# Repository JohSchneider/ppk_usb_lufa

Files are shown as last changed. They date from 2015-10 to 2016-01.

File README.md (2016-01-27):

# ppk_usb_lufa
Palm Portable Keyboard USB conversion
=====

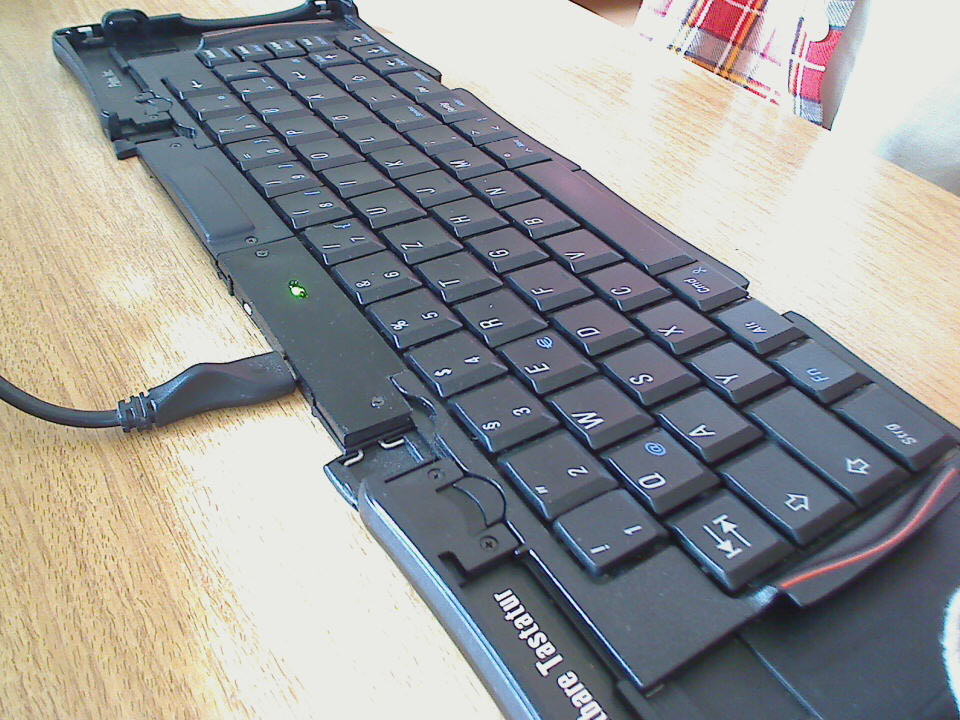
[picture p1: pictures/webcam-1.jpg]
keyboard


inspired by [this great project](http://www.cy384.com/projects/palm-keyboard.html) ([featured on Hackaday.com]([featured on HackADay](http://hackaday.com/2015/04/04/repurposing-a-palm-portable-keyboard/))

with the main goals/changes:
* keep electronics inside the fold-up case
* make it possible to use multimedia and other key-codes

the later was achieved by porting the arduino code to plain avr-c with lufa for the HID-keyboard handling and half a software serial implementation based on [application note avr309](http://www.atmel.com/Images/doc0941.pdf) (with code snippets [from here](http://www.element14.com/community/docs/DOC-56281/l/avr304-half-duplex-interrupt-driven-software-uart-on-tinyavr-and-megaavr-devices-coding))

parts list
----------
* Pololu A-Star Micro (https://www.pololu.com/product/3101) (a similar sized clone will probably do as well)
* 10k ohm 1/4W resistor
* slim tactile switch as the reset button (http://www.adafruit.com/products/1489)
* micro-usb breakout (http://www.adafruit.com/products/1833)
* wiring-pencil and wire
* 3D printed parts to replace the palm-dock

dis-assembly
---------
* remove the metal backplate on the left side (side with the palm-docking port) - take care not to cut yourself on the sharp edges
* remove the two screws connecting the fold-up stand to the keyboard followed by the two holding the docking-port
* free the flexible flat cable from the plastik parts (might need to cut some plastik away)
* desolder the spring-pins from the flat-cable

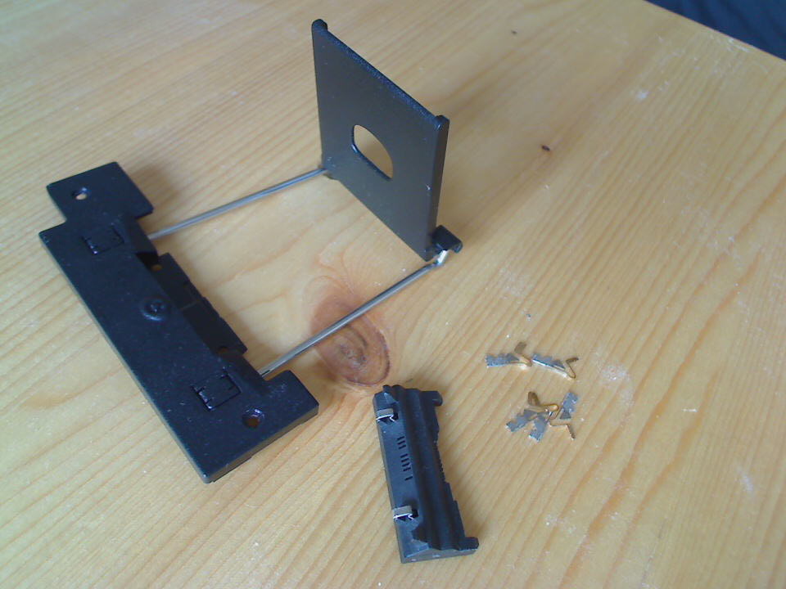
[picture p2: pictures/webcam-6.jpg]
ditched parts


* to be able to fit the Micro into the tight space its micro-usb plug needs to be desoldered (... fun)

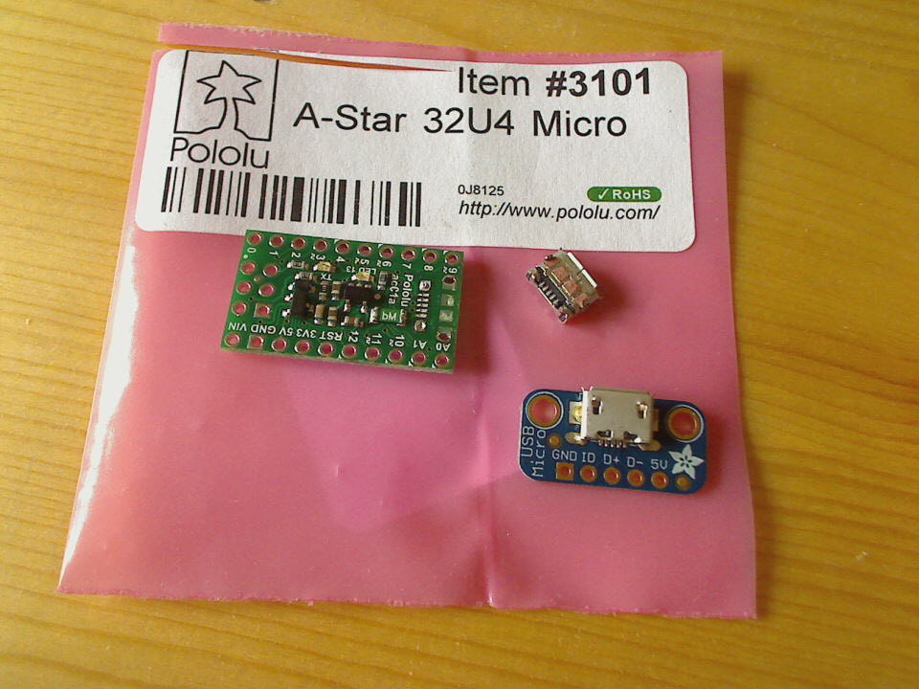
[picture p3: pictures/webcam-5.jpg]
desoldered micro-usb


wiring
--------
since these keyboards where built for multiple kinds of PDAs the dock-adapters had to be easily exchangable - that seems to be the reason why the flat cable running from the dock itself is joined to another "commmon" 6-wire flex cable with a special conductive tape that runs the remaining length around a bend to the keyboards pcb on the other side

this common flex cable has the following pinout
viewed from above - "through" the keyboard; from left to right:

Number | Name
---|---
 F1 | VCC
 F2 | RX_PIN
 F3 | RTS_PIN
 F4 | probably TX_PIN, unused anyway
 F5 | PIN_DCD
 F6 | GND

On the Micro the following pins are used:

flex cable | name | Micro Pin
--- | --- | ---
-|-|(reset to GND via the tactile switch)
 F1 | VCC | Pin 5
 F6 | GND | Pin 6
 F2 |  RX | Pin 3
 F3 | RTS | Pin 2
 F5 | DCD | Pin 4
-|-|pulldown resistor from Pin 8 to Pin 3

assembly
-------
* wire the usb-breakout to the Micro (in the final assembly the former usb port faces the micro-usb breakout)
* wire the Micro to the flex cable where the spring-pins of the docking connector used to be
* on the Micro board Gnd and Reset pins are spaced so that the reset button fits perfectly in between (covering +3V and +5V pins which need to be insulated!) putting the button on the board so that it sits flush 
* remove the support of the usb-port in the 3d printed part and *slightly* drill out the screw holes with a 3mm drill, so that the screw heads are flush with the surface
* fixing the Micro and the usb-breakout with some hot-melt glue to the 3d-printed part
* slide in the back-cover (might need to apply some heat to bend it a litte over the electronics, should close up flush with the other 3d printed part)

code compilation
---------
requires gcc-avr and avrdude to compile via the makefile

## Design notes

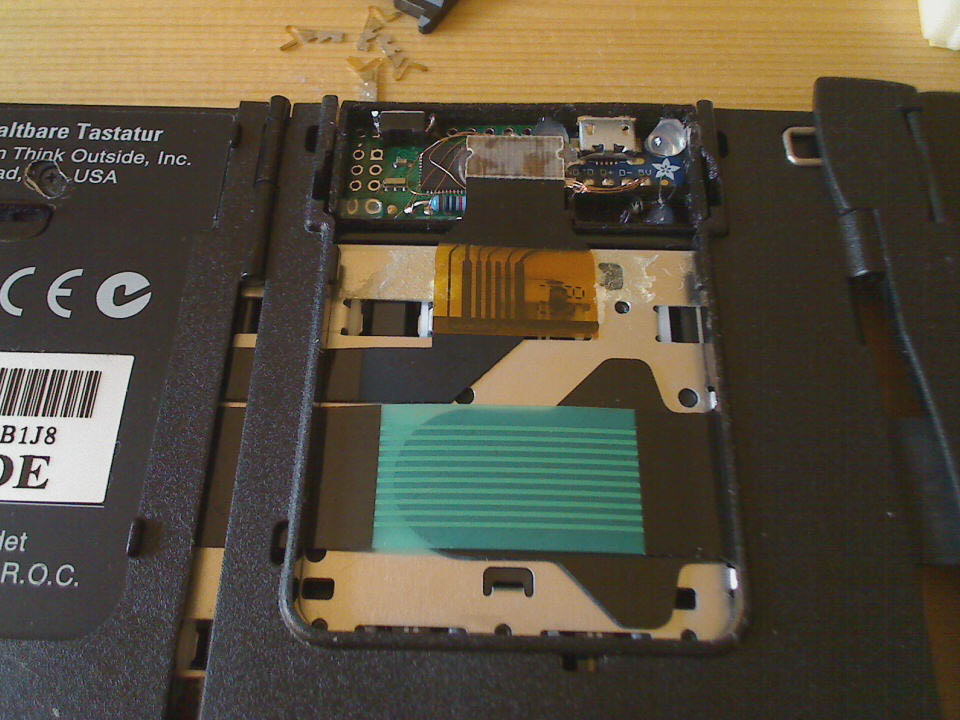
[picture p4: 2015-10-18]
pictures/webcam-7.jpg

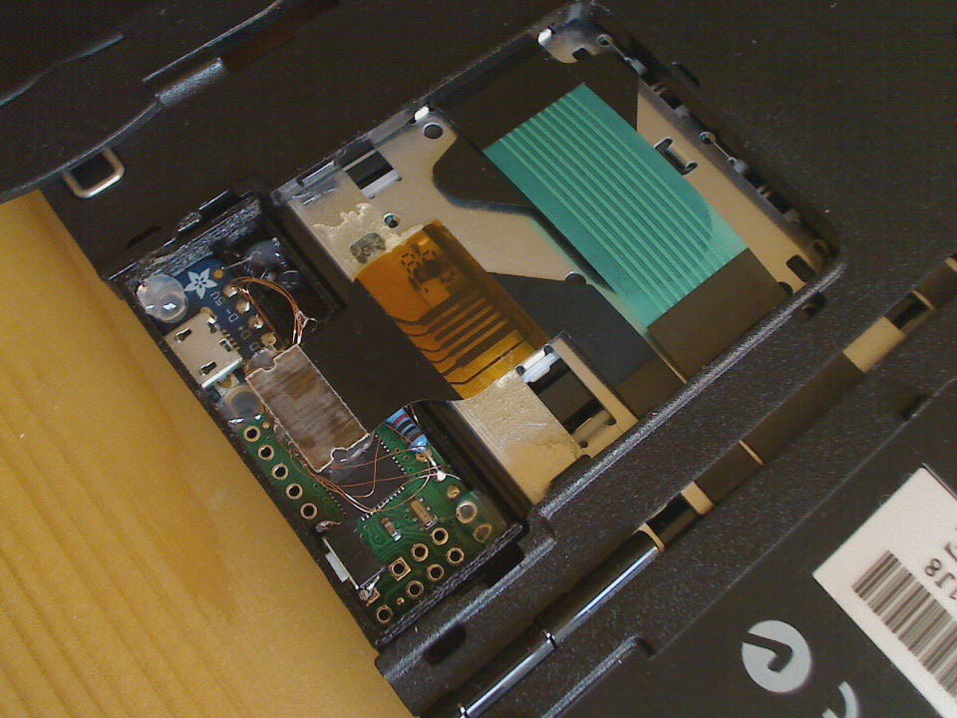
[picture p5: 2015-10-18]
pictures/webcam-8.jpg

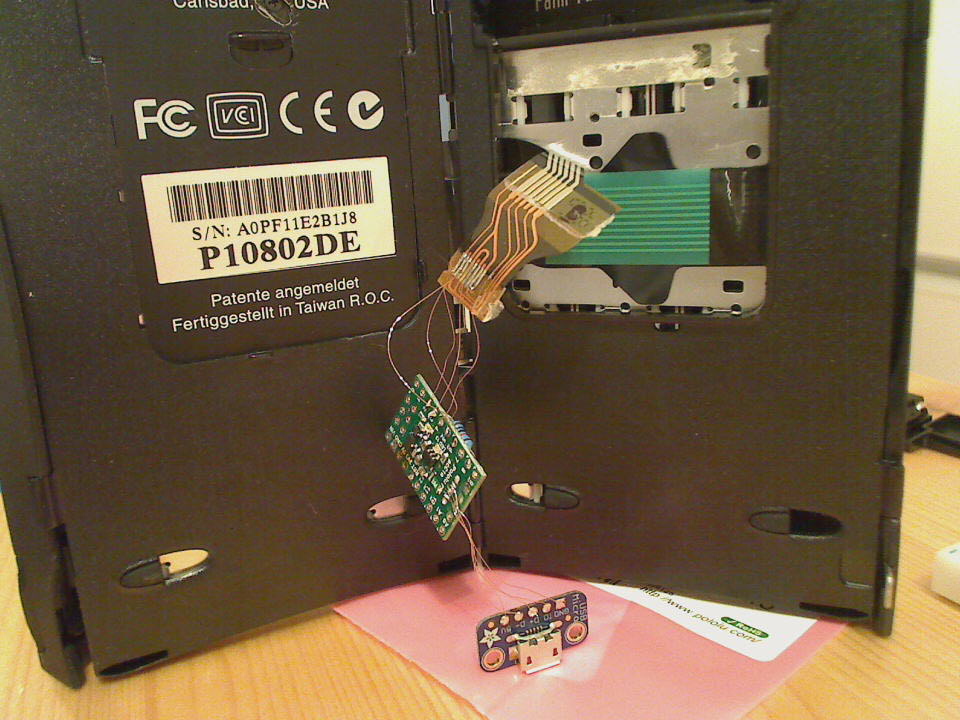
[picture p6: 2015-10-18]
pictures/webcam-3.jpg

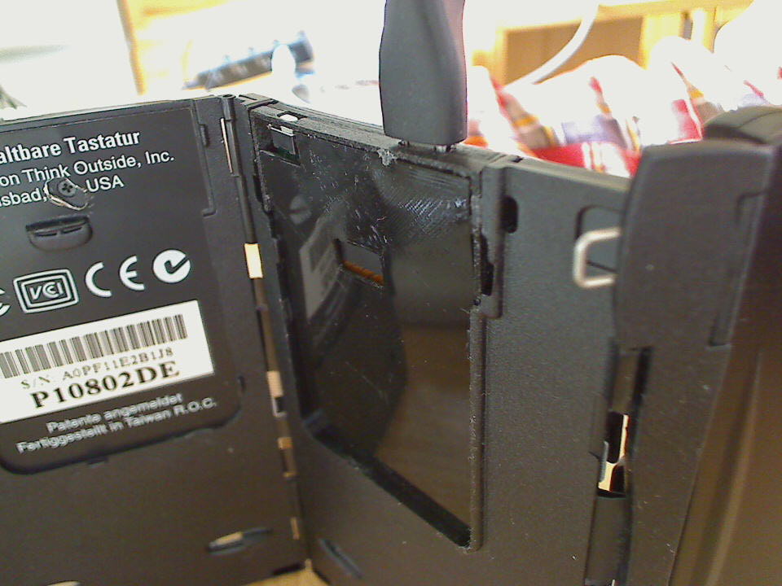
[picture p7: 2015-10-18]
pictures/webcam-4.jpg

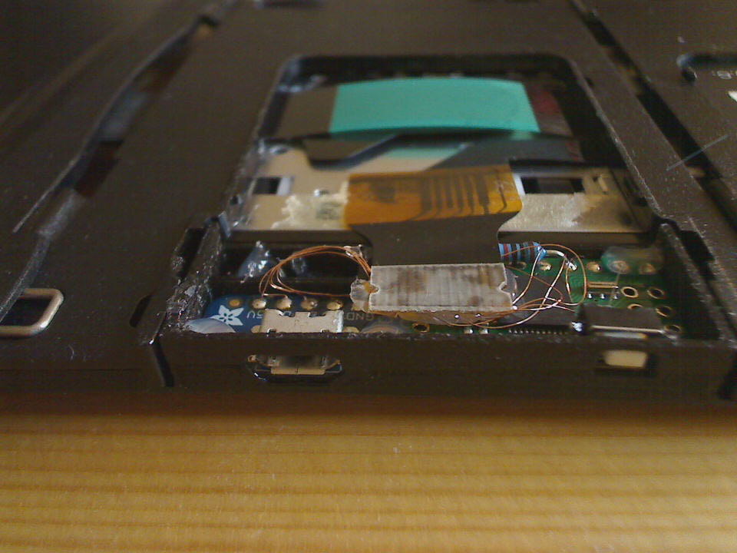
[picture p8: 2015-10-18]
pictures/webcam-9.jpg

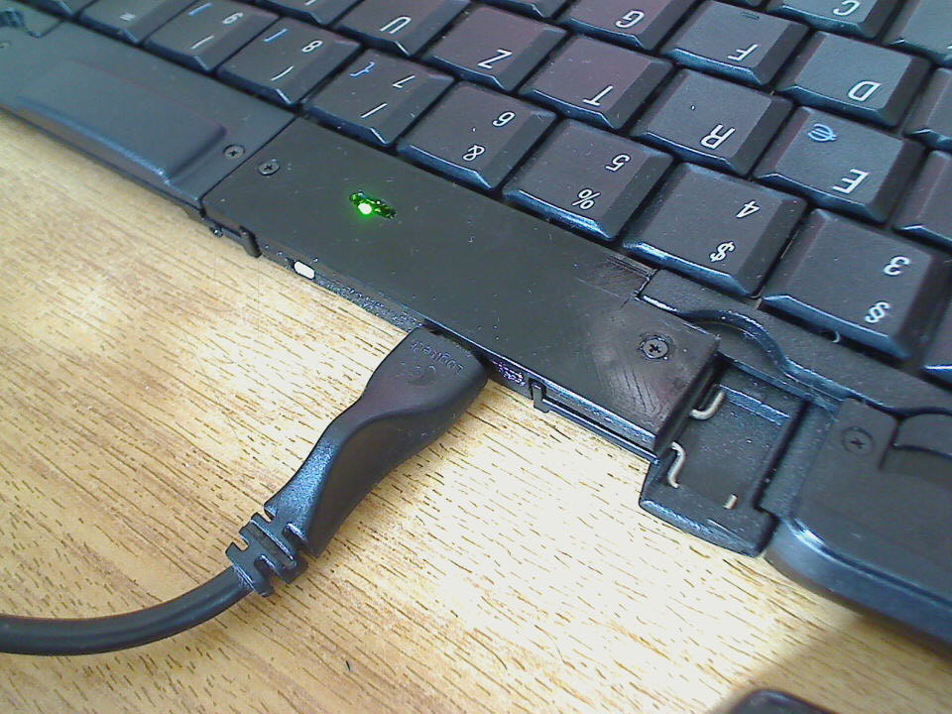
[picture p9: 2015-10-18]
pictures/webcam-2.jpg

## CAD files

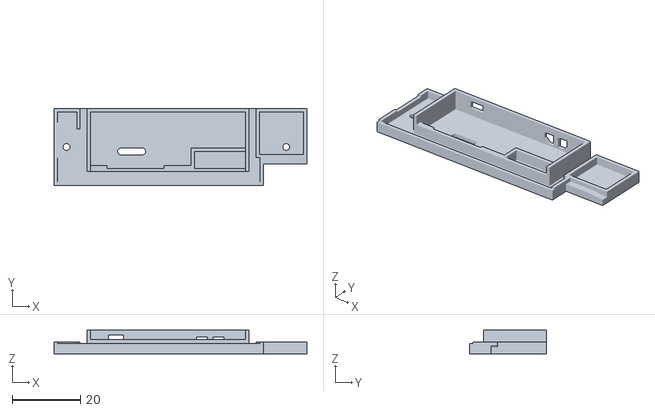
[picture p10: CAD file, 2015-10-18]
stls/palm_portable_keyboard_cover.stl
74.3 x 22.5 x 7.00

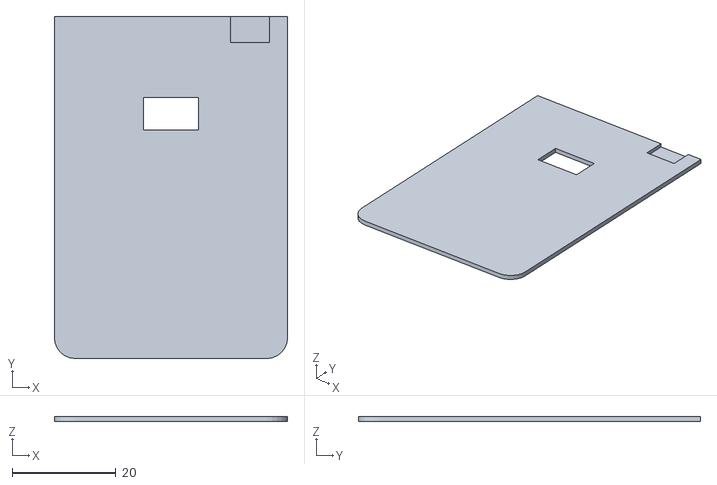
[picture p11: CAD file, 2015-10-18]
stls/palm_portable_keyboard_back_cover.stl
45.0 x 66.0 x 1.00

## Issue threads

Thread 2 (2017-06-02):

More details please and can I use a regular USB

rhubarb, 2017-06-02:
Great project: I have an old folding Palm V keyboard rendered obsolete within months of buying it and I'm itching to try out this hack.
I could use some more details though - some more photos (I can use a soldering iron but am not too experienced at this sort of hack).

Also, would it be possible to fit a regular USB on the kb, to allow reuse of a charging cable?

JohSchneider, 2017-06-07:
thnx!

maybe this is what your looking for?
https://hackaday.io/project/8107-palm-portable-keyboard-usb-mod

if a "regular usb" = USB a socket then probably no... space is quite limited
the pololu-a star micro comes with a micro-usb (which is currently more or less "the regular usb connector")

JohSchneider, 2017-06-07:
what kind of details are you looking for specifically?

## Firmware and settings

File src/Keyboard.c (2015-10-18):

/*
             LUFA Library
     Copyright (C) Dean Camera, 2015.

  dean [at] fourwalledcubicle [dot] com
           www.lufa-lib.org
*/

/*
  Copyright 2015  Dean Camera (dean [at] fourwalledcubicle [dot] com)

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
  The author disclaims all warranties with regard to this
  software, including all implied warranties of merchantability
  and fitness.  In no event shall the author be liable for any
  special, indirect or consequential damages or any damages
  whatsoever resulting from loss of use, data or profits, whether
  in an action of contract, negligence or other tortious action,
  arising out of or in connection with the use or performance of
  this software.
*/

/** \file
 *
 *  Main source file for the Keyboard demo. This file contains the main tasks of
 *  the demo and is responsible for the initial application hardware configuration.
 */

#include "Keyboard.h"

/** Buffer to hold the previously generated Keyboard HID report, for comparison purposes inside the HID class driver. */
static uint8_t PrevKeyboardHIDReportBuffer[sizeof(USB_KeyboardReport_Data_t)];

/** LUFA HID Class driver interface configuration and state information. This structure is
 *  passed to all HID Class driver functions, so that multiple instances of the same class
 *  within a device can be differentiated from one another.
 */
USB_ClassInfo_HID_Device_t Keyboard_HID_Interface =
	{
		.Config =
			{
				.InterfaceNumber              = INTERFACE_ID_Keyboard,
				.ReportINEndpoint             =
					{
						.Address              = KEYBOARD_EPADDR,
						.Size                 = KEYBOARD_EPSIZE,
						.Banks                = 1,
					},
				.PrevReportINBuffer           = PrevKeyboardHIDReportBuffer,
				.PrevReportINBufferSize       = sizeof(PrevKeyboardHIDReportBuffer),
			},
	};


/** Main program entry point. This routine contains the overall program flow, including initial
 *  setup of all components and the main program loop.
 */
int main(void)
{
	SetupHardware();

//	LEDs_SetAllLEDs(LEDMASK_USB_NOTREADY);
	LEDs_SetAllLEDs(0);

	GlobalInterruptEnable();

	BootKeyboard();

	for (;;)
	{
	  ProcessKeyboardSerialByte();
		HID_Device_USBTask(&Keyboard_HID_Interface);
		USB_USBTask();
	}
}

/** Configures the board hardware and chip peripherals for the demo's functionality. */
void SetupHardware()
{
	/* Disable watchdog if enabled by bootloader/fuses */
	MCUSR &= ~(1 << WDRF);
	wdt_disable();

	/* Disable clock division */
	clock_prescale_set(clock_div_1);


	/* Hardware Initialization */

	initSoftwareUart();

	// setup timer1 to keep the keyboard awake
	TCCR1B = (1<<CS12) | (1<<CS10); // prescaler 1024
	TCCR1B |= (1 << WGM12); // CTC mode
	TIMSK1 = 1<<OCIE1A; // trigger interrupt on compare
	OCR1A = 15624; // once per second
	// we run at 16Mhz:
	// timer counts + 1 = (target time) / (timer resolution)
	//   timer resolution = 1/(16Mhz / 1024)  seconds
	// => OCR1A = 1s * 1/( 16Mhz / 1024 ) -1 = 15624

	// setup remaining pins
	//// DCD_PIN
	// a-star micro Pin 4 -> PD4
	DDRD &= ~DCD_PIN; // set input
	//// RTS_PIN
	// a-star micro Pin 2 -> PD1
	DDRD &= ~RTS_PIN; // set input
	//// PULLDOWN_PIN
	// a-star micro Pin 8 -> PB4
	DDRB |= PULLDOWN_PIN; // set output
	PORTB &= ~PULLDOWN_PIN; // set LOW
	//// VCC_PIN
	// a-star micro Pin 5 -> PC6
	DDRC |= VCC_PIN;
	PORTC &= ~VCC_PIN;
	//// GND_PIN
	// a-star micro Pin 6 -> PD7
	DDRD |= GND_PIN;
	PORTD &= ~GND_PIN;

	USB_Init();
}

void BootKeyboard(void)
{
  PORTC &= ~VCC_PIN; // power off
  _delay_ms(5);
  PORTC |= VCC_PIN; // power on
  _delay_ms(15);

  // wait until the keyboard has powerd on, it signals this by pulling DCD_PIN high..
  while(!(PIND & DCD_PIN)) {;}
  //.. and then expects the driver to pull RTS high
  if (!(PIND & RTS_PIN)) { // if we read low
    DDRD |= RTS_PIN; // set pin to output
    PORTD |= RTS_PIN; // and high
  }
  else {
    DDRD |= RTS_PIN; // set pin to output
    PORTD &= ~RTS_PIN; // low
    _delay_ms(10);
    PORTD |= RTS_PIN; // high
  }

  _delay_ms(5);

  // wait for the keyboard to send its id string (the first two bytes)
  while (SwUartRXData != 0xFA) {;}
  while (SwUartRXData != 0xFD) {;}
}


/* keyboard goes to non-responsive sleep after 10 minutes of no keypresses and RTS on high
 * so we toggle RTS every 7 minutes regardless of input just to keep it on its toes :-)
 */
ISR(TIMER1_COMPA_vect)
{
  seconds++;
  if (seconds == 60*7)
    {
      DDRD |= RTS_PIN; // set pin to output
      PORTD &= ~RTS_PIN; // low
      _delay_ms(10);
      PORTD |= RTS_PIN; // high
      seconds = 0;
    }
}


/** press a normal key (e.g. not a modifier key) */
void pressKey(uint8_t raw, uint8_t key)
{
  if (UsedKeyCodes < 6)
    {
      UsedKeyCodes++;
      pressedRawKeyCode[UsedKeyCodes] = raw;
      KeyboardReport.KeyCode[UsedKeyCodes] = key;
    }
}

  /** release a normal, non-modifier key */
void releaseKey(uint8_t raw)
{
  // check which of the pressed KeyCode has been released
  for (int i=0; i<6; i++)
    {
      if (pressedRawKeyCode[i] == raw)
	{
	  // move remaining one place up
	  for (int j=i; j<5; j++)
	    {
	      KeyboardReport.KeyCode[j] = KeyboardReport.KeyCode[j+1];
	      pressedRawKeyCode[j] = pressedRawKeyCode[j+1];
	    }
	  // and put an empty in the last place
	  KeyboardReport.KeyCode[5] = 0;
	  pressedRawKeyCode[5] = 255;
	  UsedKeyCodes--;
	}
    }
}

void ProcessKeyboardSerialByte(void)
{
  if( state == DATA_PENDING )
    {
	      unsigned char keyUpDown = SwUartRXData & 0b10000000;
	      unsigned char keyXY = SwUartRXData & 0b01111111;
	      state = IDLE;
	      seconds = 0; // reset keep awake watchdog

	      // for a table of available keycode defines see:
	      // LUFA/Drivers/USB/Class/Common/HIDClassCommon.h

	      if (keyUpDown) // true: key released
		{
		if (lastByte == SwUartRXData)
		  {
		    // releaseAll
		    // memset(&KeyboardReport, 0, sizeof(USB_KeyboardReport_Data_t));
		    KeyboardReport.KeyCode[0] = 0;
		    KeyboardReport.KeyCode[1] = 0;
		    KeyboardReport.KeyCode[2] = 0;
		    KeyboardReport.KeyCode[3] = 0;
		    KeyboardReport.KeyCode[4] = 0;
		    KeyboardReport.KeyCode[5] = 0;
		    KeyboardReport.Modifier = 0;
		    UsedKeyCodes = 0;
		  }
		else
		  {
		    switch (keyXY)
		      {
		      case 0b00100010: // FN
			FN_pressed = 0;
			break;
		      case 0b00001000: // "CMD"
			releaseKey(keyXY);
			// TODO: is it okay to set the modifier flag and press the key at the same time?
			KeyboardReport.Modifier &= ~HID_KEYBOARD_MODIFIER_LEFTGUI;
			break;
		      case 0b00011010: // CTRL (only left one exists)
			KeyboardReport.Modifier &= ~HID_KEYBOARD_MODIFIER_LEFTCTRL;
			break;
		      case 0b00100011: // ALT (only left one exists)
			KeyboardReport.Modifier &= ~HID_KEYBOARD_MODIFIER_LEFTALT;
			break;
		      case 0b01011000: // SHIFT (L)
			KeyboardReport.Modifier &= ~HID_KEYBOARD_MODIFIER_LEFTSHIFT;
			break;
		      case 0b01011001: // SHIFT (R)
			KeyboardReport.Modifier &= ~HID_KEYBOARD_MODIFIER_RIGHTSHIFT;
			break;
		      default:
			releaseKey(keyXY);
		      }
		  }
		}
	      else // key pressed
	      switch(keyXY) {
		// y0 row
	      case 0b00000000: // '1'
		if (FN_pressed)
		  pressKey(keyXY, HID_KEYBOARD_SC_F1);
		else
		  pressKey(keyXY, HID_KEYBOARD_SC_1_AND_EXCLAMATION);
		break;
	      case 0b00000001: // '2'
		if (FN_pressed)
		  pressKey(keyXY, HID_KEYBOARD_SC_F2);
		else
		  pressKey(keyXY, HID_KEYBOARD_SC_2_AND_AT);
		break;
	      case 0b00000010: // '3'
		if (FN_pressed)
		  pressKey(keyXY, HID_KEYBOARD_SC_F3);
		else
		  pressKey(keyXY, HID_KEYBOARD_SC_3_AND_HASHMARK);
		break;
	      case 0b00000011: // 'z'
		pressKey(keyXY, HID_KEYBOARD_SC_Z);
		break;
	      case 0b00000100: // '4'
		if (FN_pressed)
		  pressKey(keyXY, HID_KEYBOARD_SC_F4);
		else
		  pressKey(keyXY, HID_KEYBOARD_SC_4_AND_DOLLAR);
		break;
	      case 0b00000101: // '5'
		if (FN_pressed)
		  pressKey(keyXY, HID_KEYBOARD_SC_F5);
		else
		  pressKey(keyXY, HID_KEYBOARD_SC_5_AND_PERCENTAGE);
		break;
	      case 0b00000110: // '6'
		if (FN_pressed)
		  pressKey(keyXY, HID_KEYBOARD_SC_F6);
		else
		  pressKey(keyXY, HID_KEYBOARD_SC_6_AND_CARET);
		break;
	      case 0b00000111: // '7'
		if (FN_pressed)
		  pressKey(keyXY, HID_KEYBOARD_SC_F7);
		else
		  pressKey(keyXY, HID_KEYBOARD_SC_7_AND_AMPERSAND);
		break;

		// y1 row
	      case 0b00001000: // "CMD"
		pressKey(keyXY, HID_KEYBOARD_SC_LEFT_GUI);
// TODO: is it okay to set the modifier flag and press the key at the same time?
		KeyboardReport.Modifier |= HID_KEYBOARD_MODIFIER_LEFTGUI;
		break;
	      case 0b00001001: // 'q'
		pressKey(keyXY, HID_KEYBOARD_SC_Q);
		break;
	      case 0b00001010: // 'w'
		pressKey(keyXY, HID_KEYBOARD_SC_W);
		break;
	      case 0b00001011: // 'e'
		pressKey(keyXY, HID_KEYBOARD_SC_E);
		break;
	      case 0b00001100: // 'r'
		pressKey(keyXY, HID_KEYBOARD_SC_R);
		break;
	      case 0b00001101: // 't'
		pressKey(keyXY, HID_KEYBOARD_SC_T);
		break;
	      case 0b00001110: // 'y'
		pressKey(keyXY, HID_KEYBOARD_SC_Y);
		break;
	      case 0b00001111: // two right of space-bar
		pressKey(keyXY, HID_KEYBOARD_SC_NON_US_BACKSLASH_AND_PIPE);  // physical row 5, 7th key
		break;

		// y2 row
	      case 0b00010000: // 'x'
		pressKey(keyXY, HID_KEYBOARD_SC_X);
		break;
	      case 0b00010001: // 'a'
		pressKey(keyXY, HID_KEYBOARD_SC_A);
		break;
	      case 0b00010010: // 's'
		pressKey(keyXY, HID_KEYBOARD_SC_S);
		break;
	      case 0b00010011: // 'd'
		pressKey(keyXY, HID_KEYBOARD_SC_D);
		break;
	      case 0b00010100: // 'f'
		pressKey(keyXY, HID_KEYBOARD_SC_F);
		break;
	      case 0b00010101: // 'g'
		pressKey(keyXY, HID_KEYBOARD_SC_G);
		break;
	      case 0b00010110: // 'h'
		pressKey(keyXY, HID_KEYBOARD_SC_H);
		break;
	      case 0b00010111: // ' ' // "Space 1"
		pressKey(keyXY, HID_KEYBOARD_SC_SPACE);
		break;

		// y3 row
	      case 0b00011000: // CAPS LK
		pressKey(keyXY, HID_KEYBOARD_SC_CAPS_LOCK);
		break;
	      case 0b00011001: // TAB
		pressKey(keyXY, HID_KEYBOARD_SC_TAB);
		break;
	      case 0b00011010: // CTRL (only left one exists)
		KeyboardReport.Modifier |= HID_KEYBOARD_MODIFIER_LEFTCTRL;
		break;

		// y4 row
	      case 0b00100010: // FN
		FN_pressed = 1;
		break;
	      case 0b00100011: // ALT (only left one exists)
		KeyboardReport.Modifier |= HID_KEYBOARD_MODIFIER_LEFTALT;
		break;

		// y5 row
	      case 0b00101100: // 'c'
		pressKey(keyXY, HID_KEYBOARD_SC_C);
		break;
	      case 0b00101101: // 'v'
		pressKey(keyXY, HID_KEYBOARD_SC_V);
		break;
	      case 0b00101110: // 'b'
		pressKey(keyXY, HID_KEYBOARD_SC_B);
		break;
	      case 0b00101111: // 'n'
		pressKey(keyXY, HID_KEYBOARD_SC_N);
		break;

		// y6 row
	      case 0b00110000: // '-'
		if (FN_pressed)
		  pressKey(keyXY, HID_KEYBOARD_SC_F11);
		else
		  pressKey(keyXY, HID_KEYBOARD_SC_MINUS_AND_UNDERSCORE);
		break;
	      case 0b00110001: // '='
		if (FN_pressed)
		  pressKey(keyXY, HID_KEYBOARD_SC_F12);
		else
		  pressKey(keyXY, HID_KEYBOARD_SC_EQUAL_AND_PLUS);
		break;
	      case 0b00110010: // BACK SP
		pressKey(keyXY, HID_KEYBOARD_SC_BACKSPACE);
		break;
	      case 0b00110011: // "Special Function One"
		pressKey(keyXY, HID_KEYBOARD_SC_MEDIA_NEXT_TRACK);
		break;
	      case 0b00110100: // '8'
		if (FN_pressed)
		  pressKey(keyXY, HID_KEYBOARD_SC_F8);
		else
		  pressKey(keyXY, HID_KEYBOARD_SC_8_AND_ASTERISK);
		break;
	      case 0b00110101: // '9'
		if (FN_pressed)
		  pressKey(keyXY, HID_KEYBOARD_SC_F9);
		else
		  pressKey(keyXY, HID_KEYBOARD_SC_9_AND_OPENING_PARENTHESIS);
		break;
	      case 0b00110110: // '0'
		if (FN_pressed)
		  pressKey(keyXY, HID_KEYBOARD_SC_F10);
		else
		  pressKey(keyXY, HID_KEYBOARD_SC_0_AND_CLOSING_PARENTHESIS);
		break;
	      case 0b00110111: // "Space 2" - Note: right of space-bar
		pressKey(keyXY, HID_KEYBOARD_SC_GRAVE_ACCENT_AND_TILDE); // physical row 5, 6th key
		break;

		// y7 row
	      case 0b00111000: // '['
		pressKey(keyXY, HID_KEYBOARD_SC_OPENING_BRACKET_AND_OPENING_BRACE);
		break;
	      case 0b00111001: // ']'
		pressKey(keyXY, HID_KEYBOARD_SC_CLOSING_BRACKET_AND_CLOSING_BRACE);
		break;
	      case 0b00111010: // '\'
		pressKey(keyXY, HID_KEYBOARD_SC_BACKSLASH_AND_PIPE);
		break;
	      case 0b00111011: // "Special Function Two"
		pressKey(keyXY, HID_KEYBOARD_SC_MEDIA_PREVIOUS_TRACK);
		break;
	      case 0b00111100: // 'u'
		pressKey(keyXY, HID_KEYBOARD_SC_U);
		break;
	      case 0b00111101: // 'i'
		pressKey(keyXY, HID_KEYBOARD_SC_I);
		break;
	      case 0b00111110: // 'o'
		pressKey(keyXY, HID_KEYBOARD_SC_O);
		break;
	      case 0b00111111: // 'p'
		pressKey(keyXY, HID_KEYBOARD_SC_P);
		break;

		// y8 row
	      case 0b01000000: // '''
		pressKey(keyXY, HID_KEYBOARD_SC_APOSTROPHE_AND_QUOTE);
		break;
	      case 0b01000001: // ENTER
		pressKey(keyXY, HID_KEYBOARD_SC_ENTER);
		break;
	      case 0b01000010: // "Special Function Three"
		pressKey(keyXY, HID_KEYBOARD_SC_MEDIA_VOLUME_UP);
		break;
	      case 0b01000100: // 'j'
		pressKey(keyXY, HID_KEYBOARD_SC_J);
		break;
	      case 0b01000101: // 'k'
		pressKey(keyXY, HID_KEYBOARD_SC_K);
		break;
	      case 0b01000110: // 'l'
		pressKey(keyXY, HID_KEYBOARD_SC_L);
		break;
	      case 0b01000111: // ';'
		pressKey(keyXY, HID_KEYBOARD_SC_SEMICOLON_AND_COLON);
		break;

		// y9 row
	      case 0b01001000: // '?'
		pressKey(keyXY, HID_KEYBOARD_SC_SLASH_AND_QUESTION_MARK);
		break;
	      case 0b01001001: // up arrow
		if (FN_pressed)
		  pressKey(keyXY, HID_KEYBOARD_SC_PAGE_UP);
		else
		  pressKey(keyXY, HID_KEYBOARD_SC_UP_ARROW);
		break;
	      case 0b01001010: // "Special Function Four"
		pressKey(keyXY, HID_KEYBOARD_SC_MEDIA_VOLUME_DOWN);
		break;
	      case 0b01001100: // 'm'
		pressKey(keyXY, HID_KEYBOARD_SC_M);
		break;
	      case 0b01001101: // ','
		pressKey(keyXY, HID_KEYBOARD_SC_COMMA_AND_LESS_THAN_SIGN);
		break;
	      case 0b01001110: // '.'
		pressKey(keyXY, HID_KEYBOARD_SC_DOT_AND_GREATER_THAN_SIGN);
		break;
	      case 0b01001111: // "DONE"
		pressKey(keyXY, HID_KEYBOARD_SC_ESCAPE);
		break;

		// y10 row
	      case 0b01010000: // DEL
		if (FN_pressed)
		  pressKey(keyXY, HID_KEYBOARD_SC_INSERT);
		else
		  pressKey(keyXY, HID_KEYBOARD_SC_DELETE);
		break;
	      case 0b01010001: // left arrow
		if (FN_pressed)
		  pressKey(keyXY, HID_KEYBOARD_SC_HOME);
		else
		  pressKey(keyXY, HID_KEYBOARD_SC_LEFT_ARROW);
		break;
	      case 0b01010010: // down arrow
		if (FN_pressed)
		  pressKey(keyXY, HID_KEYBOARD_SC_PAGE_DOWN);
		else
		  pressKey(keyXY, HID_KEYBOARD_SC_DOWN_ARROW);
		break;
	      case 0b01010011: // right arrow
		if (FN_pressed)
		  pressKey(keyXY, HID_KEYBOARD_SC_END);
		else
		  pressKey(keyXY, HID_KEYBOARD_SC_RIGHT_ARROW);
		break;

		// y11 row
	      case 0b01011000: // SHIFT (L)
		KeyboardReport.Modifier |= HID_KEYBOARD_MODIFIER_LEFTSHIFT;
		break;
	      case 0b01011001: // SHIFT (R)
		KeyboardReport.Modifier |= HID_KEYBOARD_MODIFIER_RIGHTSHIFT;
		break;
	      }

	      lastByte = SwUartRXData;
	  }
}


/** Event handler for the library USB Connection event. */
void EVENT_USB_Device_Connect(void)
{
//	LEDs_SetAllLEDs(LEDMASK_USB_ENUMERATING);
}

/** Event handler for the library USB Disconnection event. */
void EVENT_USB_Device_Disconnect(void)
{
//	LEDs_SetAllLEDs(LEDMASK_USB_NOTREADY);
}

/** Event handler for the library USB Configuration Changed event. */
void EVENT_USB_Device_ConfigurationChanged(void)
{
	bool ConfigSuccess = true;

	ConfigSuccess &= HID_Device_ConfigureEndpoints(&Keyboard_HID_Interface);

	USB_Device_EnableSOFEvents();

//	LEDs_SetAllLEDs(ConfigSuccess ? LEDMASK_USB_READY : LEDMASK_USB_ERROR);
}

/** Event handler for the library USB Control Request reception event. */
void EVENT_USB_Device_ControlRequest(void)
{
	HID_Device_ProcessControlRequest(&Keyboard_HID_Interface);
}

/** Event handler for the USB device Start Of Frame event. */
void EVENT_USB_Device_StartOfFrame(void)
{
	HID_Device_MillisecondElapsed(&Keyboard_HID_Interface);
}

/** HID class driver callback function for the creation of HID reports to the host.
 *
 *  \param[in]     HIDInterfaceInfo  Pointer to the HID class interface configuration structure being referenced
 *  \param[in,out] ReportID    Report ID requested by the host if non-zero, otherwise callback should set to the generated report ID
 *  \param[in]     ReportType  Type of the report to create, either HID_REPORT_ITEM_In or HID_REPORT_ITEM_Feature
 *  \param[out]    ReportData  Pointer to a buffer where the created report should be stored
 *  \param[out]    ReportSize  Number of bytes written in the report (or zero if no report is to be sent)
 *
 *  \return Boolean \c true to force the sending of the report, \c false to let the library determine if it needs to be sent
 */
bool CALLBACK_HID_Device_CreateHIDReport(USB_ClassInfo_HID_Device_t* const HIDInterfaceInfo,
                                         uint8_t* const ReportID,
                                         const uint8_t ReportType,
                                         void* ReportData,
                                         uint16_t* const ReportSize)
{
//	USB_KeyboardReport_Data_t* KeyboardReport = (USB_KeyboardReport_Data_t*)ReportData;
//	uint8_t UsedKeyCodes = 0;
//  if (UsedKeyCodes > 0)
    {
      memcpy(ReportData, &KeyboardReport, sizeof(USB_KeyboardReport_Data_t));
      //      UsedKeyCodes = 0;
    }


	*ReportSize = sizeof(USB_KeyboardReport_Data_t);
	return false;
}

/** HID class driver callback function for the processing of HID reports from the host.
 *
 *  \param[in] HIDInterfaceInfo  Pointer to the HID class interface configuration structure being referenced
 *  \param[in] ReportID    Report ID of the received report from the host
 *  \param[in] ReportType  The type of report that the host has sent, either HID_REPORT_ITEM_Out or HID_REPORT_ITEM_Feature
 *  \param[in] ReportData  Pointer to a buffer where the received report has been stored
 *  \param[in] ReportSize  Size in bytes of the received HID report
 */
void CALLBACK_HID_Device_ProcessHIDReport(USB_ClassInfo_HID_Device_t* const HIDInterfaceInfo,
                                          const uint8_t ReportID,
                                          const uint8_t ReportType,
                                          const void* ReportData,
                                          const uint16_t ReportSize)
{
	uint8_t  LEDMask   = LEDS_NO_LEDS;
	uint8_t* LEDReport = (uint8_t*)ReportData;

//	if (*LEDReport & HID_KEYBOARD_LED_NUMLOCK)
//	  LEDMask |= LEDS_LED1;

	if (*LEDReport & HID_KEYBOARD_LED_CAPSLOCK)
	  LEDMask |= LEDS_LED1;

//	if (*LEDReport & HID_KEYBOARD_LED_SCROLLLOCK)
//	  LEDMask |= LEDS_LED4;

	LEDs_SetAllLEDs(LEDMask);
}


/////////////////////////////////////////////////////////////
///// Software UART
////
/// after
/// http://www.atmel.com/Images/doc0941.pdf "AVR304: Half Duplex Interrupt Driven Software UART"
/// http://www.element14.com/community/docs/DOC-56281/l/avr304-half-duplex-interrupt-driven-software-uart-on-tinyavr-and-megaavr-devices-coding

#define BAUDRATE 9600
#define RX_PIN 0               //!< Receive data pin, must be INT0
#define INVERT_LEVELS 1 // 0: use standard active low signal levels - 1: use active high

#define TRXDDR  DDRD
#define TRXPORT PORTD
#define TRXPIN  PIND

#define GET_RX_PIN( )    ( TRXPIN & ( 1 << RX_PIN ) )

// chip specific configuration
#define ENABLE_TIMER_INTERRUPT( )       ( TIMSK0 |= ( 1<< OCIE0A ) )
#define DISABLE_TIMER_INTERRUPT( )      ( TIMSK0 &= ~( 1<< OCIE0A ) )
#define CLEAR_TIMER_INTERRUPT( )        ( TIFR0 |= ((1 << OCF0A) ) )
#define ENABLE_EXTERNAL0_INTERRUPT( )   ( EIMSK |= ( 1<< INT0 ) )
#define DISABLE_EXTERNAL0_INTERRUPT( )  ( EIMSK &= ~( 1<< INT0 ) )
#define TCCR             TCCR0A             //!< Timer/Counter Control Register
#define TCCR_P           TCCR0B             //!< Timer/Counter Control (Prescaler) Register
#define OCR              OCR0A              //!< Output Compare Register
#define EXT_IFR          EIFR              //!< External Interrupt Flag Register
#define EXT_ICR          EICRA             //!< External Interrupt Control Register
#define TIMER_COMP_VECT  TIMER0_COMPA_vect  //!< Timer Compare Interrupt Vector

// some magic number?
#define INTERRUPT_EXEC_CYCL   9       //!< Cycles to execute interrupt rutine from interrupt.

//#define C 8 // used prescaling factor for timer0
//#define N   (F_CPU / BAUDRATE / C) // N = Xcal / (Baud * C)
//#define TICKS2WAITONE       N  //!< Wait one bit period.
//#define TICKS2WAITONE_HALF  (N+N/2)  //!< Wait one and a half bit period.
//#define TICKS2WAITONE 208U /// 16000000 / (9600 * 8)
//#define TICKS2WAITONE_HALF 312U //!! larger then 8bit whooops
#define TICKS2WAITONE 26 /// 16000000 / (9600 * 64)
#define TICKS2WAITONE_HALF 39

//#define STR_HELPER(x) #x
//#define STR(x) STR_HELPER(x)
//#pragma message "content of N: " STR(N)

static void initSoftwareUart( void )
{
  //PORT
  TRXPORT |= ( 1 << RX_PIN );       // RX_PIN is input, tri-stated.

  // Timer0
  DISABLE_TIMER_INTERRUPT( );
  TCCR = 0x00;    //Init.
  TCCR_P = 0x00;    //Init.
  TCCR |= (1 << WGM01);			// Timer in CTC mode.
  TCCR_P |=  ( 1 << CS01 ) | (1<<CS00);        // Divide by 64 prescaler.

  //External interrupt
  EXT_ICR = 0x00;                   // Init.

#if INVERT_LEVELS
  EXT_ICR |= ( 1 << ISC01 ) | ( 1 << ISC00 );        // Interrupt sense control: rising edge.
#else
  EXT_ICR |= ( 1 << ISC01 );        // Interrupt sense control: falling edge.
#endif
  ENABLE_EXTERNAL0_INTERRUPT( );    // Turn external interrupt on.

  //Internal State Variable
  state = IDLE;
}
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
